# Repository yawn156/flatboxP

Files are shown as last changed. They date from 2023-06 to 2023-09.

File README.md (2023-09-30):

# FlatboxP: Flatbox rev5 fork 

This fork is now using WS2812B-V5 from JLC, which include capacitors inside the circuit and also operate on 3.3v logic from the RP2040.
Switch footprint supports Kaihl choc v1 and v2.

For the case I remixed Pettman's flatbox5 case to have a little window to show the active area of the screen.
I'll only upload the remixed top case here, go to their repo for details and the bottom plate (I remixed the model that allows for threaded inserts so make sure to grab some M2x4 brass inserts.):
https://github.com/pett-j/Flatbox-rev5-remix

If you want to use Choc V1 switches I recommend getting chocfox keycaps and using this button model:
https://www.thingiverse.com/thing:6196955

For V2 switches you can use SGF's buttons:
https://github.com/sgfdevices/Bridget/tree/main/Buttons

3D Printed Tact switch buttons:
https://www.printables.com/model/470120-flatbox-tactile-switch-button

This repository contains a 3D-printable model and PCB design files to make an arcade controller that looks like this:

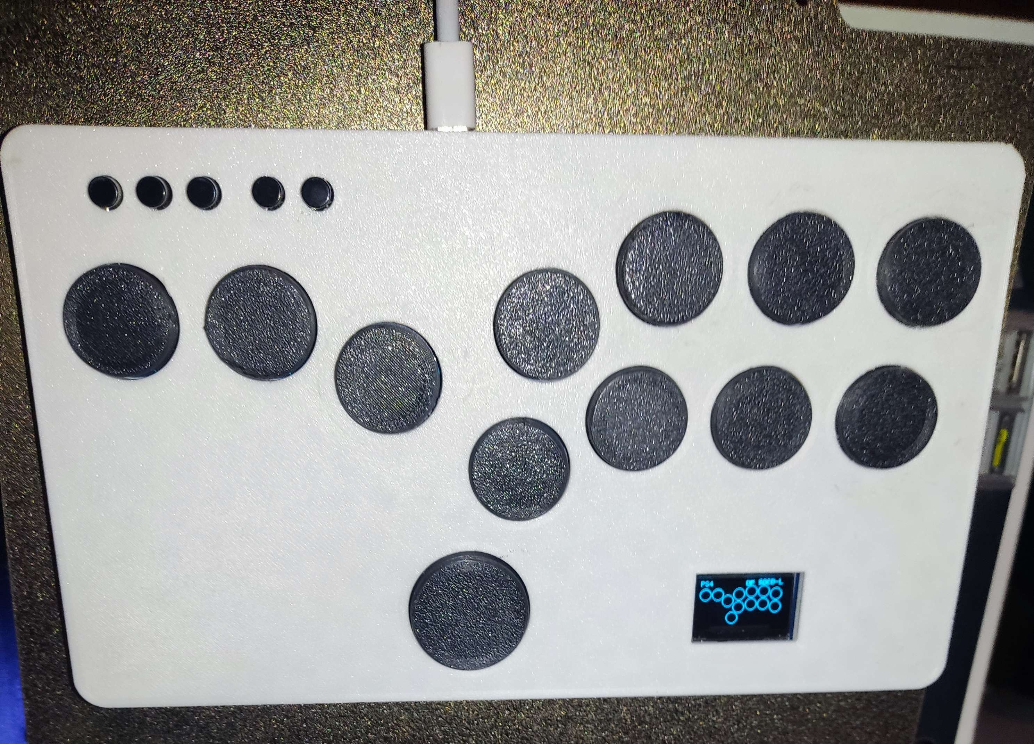
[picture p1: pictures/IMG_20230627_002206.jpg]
Assembled Flatbox


Note: Cheatbuttons are two extra buttons for easy thumb access, they have been added on the pcb but the case is still WIP.

MISC INFO:
As I'm not keeping up with this project enough to have an updated build version with every release I'll note here the changes on the webconfigurator that you need to do in order for this to work, you can use the Flatbox rev5 or Flatbox rev5 RGB uf2 from the GP2040-CE repository.

-Display Configuration:

Use Display = Enabled

SDA Pin = 0

SCL Pin = 1

-RGB LED Configuration:

Data Pin = 29

LED layout = Hit Box Layout

Leds per button = 1

-Pin Mapping

S1 = 15

S2 = 14

L3 = 27

R3 = 28

A1 = 26

A2 = -1

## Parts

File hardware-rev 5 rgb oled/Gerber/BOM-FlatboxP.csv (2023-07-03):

Comment | Designator | Footprint | LCSC
SW_Push | HOME1,L3,R3,SELECT1,START1 | SW_PUSH_6mm_H5mm | C2837518
WS2812B | D1,D10,D11,D12,D2,D3,D4,D5,D6,D7,D8,D9 | LED_WS2812B_PLCC4_5.0x5.0mm_P3.2mm | C2874885
SW_Push | SW18 | Kailh_socket_PG1350_reversible
MountingHole | H1 | MountingHole_6.4mm_M6
MountingHole | H4 | MountingHole_6.4mm_M6
MountingHole | H6 | MountingHole_6.4mm_M6
MountingHole | H3 | MountingHole_6.4mm_M6
MountingHole | H2 | MountingHole_6.4mm_M6
MountingHole | H7 | MountingHole_6.4mm_M6
MountingHole | H5 | MountingHole_6.4mm_M6
RP2040-Zero | A1 | RP2040-Zero
SSD1306 | OLED1 | 128x64OLED
SW_Push | cheatbutton01 | Kailh_socket_PG1350_reversible
SW_Push | cheatbutton02 | Kailh_socket_PG1350_reversible
SW_Push | SW8 | Kailh_socket_PG1350_reversible
SW_Push | SW9 | Kailh_socket_PG1350_reversible
SW_Push | SW10 | Kailh_socket_PG1350_reversible
SW_Push | SW11 | Kailh_socket_PG1350_reversible
SW_Push | SW12 | Kailh_socket_PG1350_reversible
SW_Push | SW13 | Kailh_socket_PG1350_reversible
SW_Push | SW14 | Kailh_socket_PG1350_reversible
SW_Push | SW15 | Kailh_socket_PG1350_reversible
SW_Push | SW16 | Kailh_socket_PG1350_reversible
SW_Push | SW17 | Kailh_socket_PG1350_reversible
SW_Push | SW7 | Kailh_socket_PG1350_reversible

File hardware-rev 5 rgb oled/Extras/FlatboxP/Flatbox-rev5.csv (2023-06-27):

# | Reference | Qty | Value | Footprint | DNP
1 | A1 | 1 | RP2040-Zero | RP2040-Zero:RP2040-Zero
2 | D1, D2, D3, D4, D5, D6, D7, D8, D9, D10, D11, D12 | 12 | WS2812B | LED_SMD:LED_WS2812B_PLCC4_5.0x5.0mm_P3.2mm
3 | H1, H2, H3, H4, H5, H6, H7 | 7 | MountingHole | MountingHole:MountingHole_6.4mm_M6
4 | OLED1 | 1 | SSD1306 | SSD1306:128x64OLED
5 | SW1, SW2, SW3, SW4, SW5 | 5 | SW_Push | Button_Switch_THT:SW_PUSH_6mm_H5mm
6 | SW7, SW8, SW9, SW10, SW11, SW12, SW13, SW14, SW15, SW16, SW17, SW18 | 12 | SW_Push | kaihl reversible:Kailh_socket_PG1350_reversible

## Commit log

2023-04-21 Add files via upload
    WIP will update when boards arrive
2023-06-24 Add files via upload
    Kicad project files
    WARNING: RGB LED circuit needs to be redone!!
    these have a backwards sk6812-mini footprint, I'll fix this when I have time (probably change them to ws2812-bs)
    OLED screen works with a ssd1306 fine.
    [Flatbox-rev5.kicad_pcb, Flatbox-rev5.kicad_sch]
2023-06-24 add case files
    For the case I remixed Pettman's flatbox5 case
    I'll only upload the remixed top case here, go to their repo for details and the bottom plate:
    https://github.com/pett-j/Flatbox-rev5-remix
2023-06-27 Add files via upload
    production files, untested
    using WS2812B-B/T which supposedly work with 3.3v logic
    [BOM-FlatboxP.csv, Flatbox-rev5.csv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]
2023-06-27 Add files via upload
    production files, RGB circuit using WS2812B-B/Ts which supposedly work with 3.3v logic
    WARNING: UNTESTED!!!!!!!!!!!
    [BOM-FlatboxP.csv, Flatbox-rev5.csv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]
2023-06-27 Add files via upload
    Using SGF's v1/v2 footprint, edited because I'm not using the reversible hotswap
    WARNING: UNTESTED
    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
    [Flatbox-rev5.csv, Flatbox-rev5.kicad_pcb, Flatbox-rev5.kicad_sch]
2023-06-30 Add files via upload
    updated case remix with pettman's new case, now uses m2.5x4 heat inserts.
2023-07-03 small gerber revision
    added tact switches as an option for jlc assembly and optimized some traces. :p
    [BOM-FlatboxP.csv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]
2023-07-03 latest project files
    [Flatbox-rev5.csv, Flatbox-rev5.kicad_pcb, Flatbox-rev5.kicad_sch]
2023-07-03 Add gp2040-CE gpio config files
    This sets the correct pins for the front panel buttons since I used the SHARE one as a i2c pin for the oled. layout ends as START/SELECT/HOME/L3/R3.
    Also sets the OLED's SDA/SCL pins and enables the function on the screen display tab of the webconfig.
